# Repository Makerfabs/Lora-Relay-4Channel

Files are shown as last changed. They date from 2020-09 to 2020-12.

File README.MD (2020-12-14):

 Lora-Relay-4Channel
 ==
Introduce
-
4-Channel Lora Relay-10A based on the Arduino, users can program it with Arduino IDE, which is very easy especially suit for the none-programmers. There are also guide for users to learn how to create the first IoT project with this board, with which the starters can learn the hardware and programming skill quickly. <br>
[Makerfabs Wiki](https://makerfabs.com/wiki/index.php?title=Main_Page) <br>
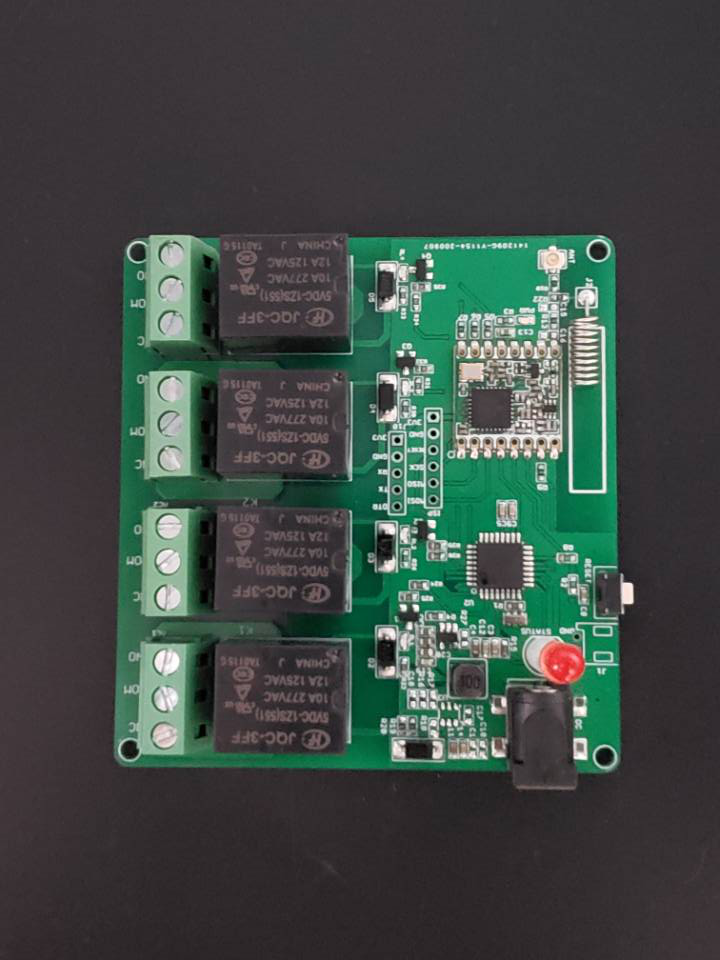
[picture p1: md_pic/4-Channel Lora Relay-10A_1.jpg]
<br/>

Feature
-
* ATMEL Atmega328P: High Performance, Low Power Atmel®AVR® 8-Bit Microcontroller
* Speed Grade:20Mhz
* Flash:32Kbytes
* RAM: 2KBytes
* EEPROM: 1Kbytes
* Relay type: General Purpose 
* Rated current of relay contact: 10A
* Coil type of relay: Non Latching
* Coil voltage of relay: 5V
* Switching voltage of relay: (277VAC , 28VDC) Max
* DC12V or 5V input

Usage
-
 ### Hardware connection
The USB TO UART TOOL is needed to connect the module and PC. <br>
The pins connections is: 
|4-Channel Lora Relay-10A |USB-to-UART Tool |
|---|---|
|3V3 |3V3 |
|GND |GND |
|RX |TXD |
|TX |RXD |

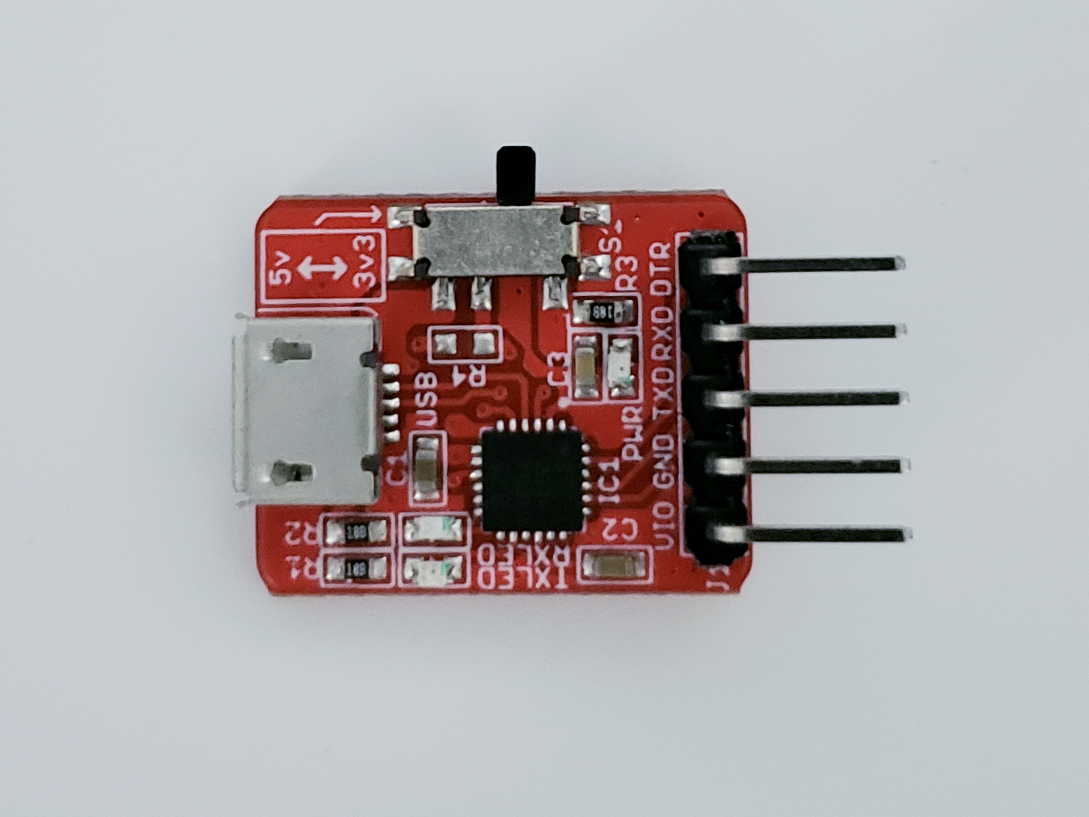
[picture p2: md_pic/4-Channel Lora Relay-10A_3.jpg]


 ### Software setup
Open the Arduino, select the tools menu and set the parameter, as the figure:<br>
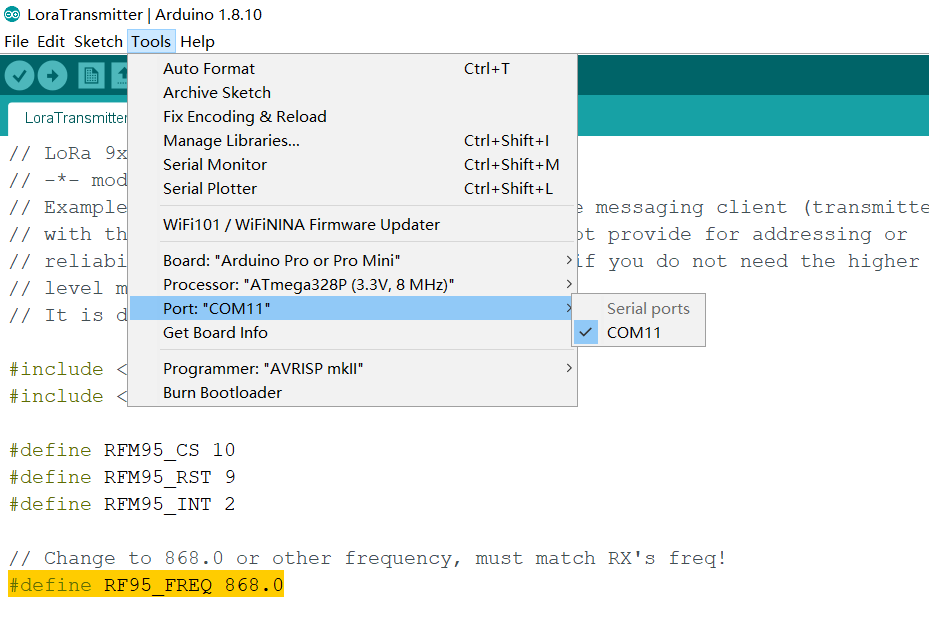
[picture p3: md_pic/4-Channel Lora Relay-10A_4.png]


 ### Lora Transmitter
Prepare a Lora receiver and put it aside.<br>
Open the code "LoraTransmitter/LoraTransmitter.ino" and modify the frequency macro according to your board is 433Mhz or 868Mhz or 915Mhz. <br>
```
#define RF95_FREQ 868.0  
```
Verify and upload it. <br>
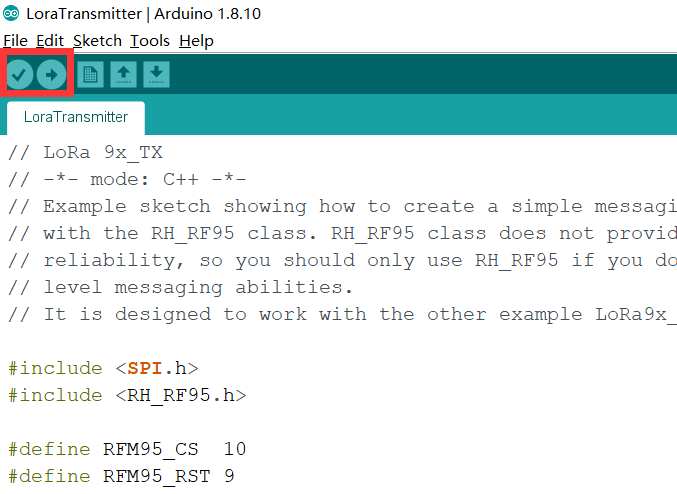
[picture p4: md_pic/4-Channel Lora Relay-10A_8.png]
  <br>
Open the “Tools—Serial Monitor” and the information of Lora Transmitter will be shown in the monitor, as the picture. 
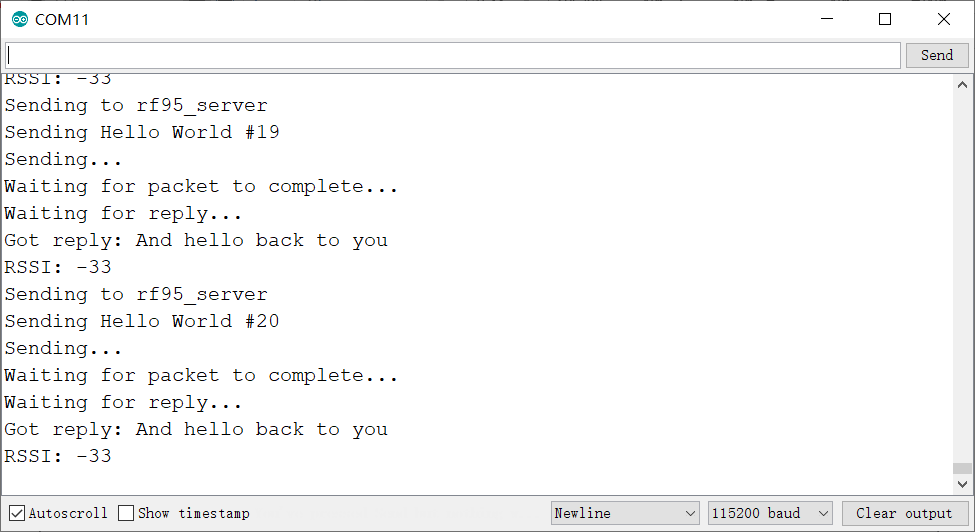
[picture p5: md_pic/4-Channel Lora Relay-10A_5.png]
 

 ### Lora receiver
Open the "LoraReceiver/LoraReceiver.ino" and modify the frequency macro according to your board is 433Mhz or 868Mhz or 915Mhz. 
```
#define RF95_FREQ 868.0 
```
Verify and upload it. After finish, open the “Tools—Serial Monitor”, If have a transmitter next to it, the receive will receive data sent by the Transmitter and the monitor will show the received information in the window, as the picture.
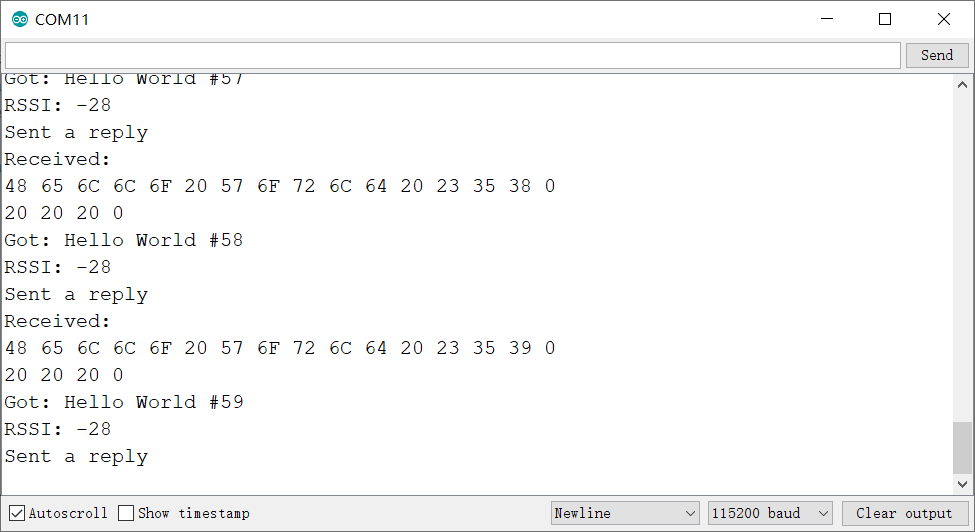
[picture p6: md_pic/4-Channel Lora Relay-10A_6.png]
  <br>
If the receiver has received it, the relay will be turned on or turned off. Light on when COM connect to NO, light off when COM connect to NC and Normally light off.<br>
 <br>
Control relay pins: <br>
|Atmega328P	|Relay |
|---|---|
|D4	|K1 |
|D3	|K2 |
|A3	|K3 |
|A2	|K4 |

The following table lists all of the relay's pins and their functionality.<br>
|Pin	|Description | 
|---|---|
|NC	Normally |Closed | 
|NO	Normally |Opened | 
|COM	|Switch Common |

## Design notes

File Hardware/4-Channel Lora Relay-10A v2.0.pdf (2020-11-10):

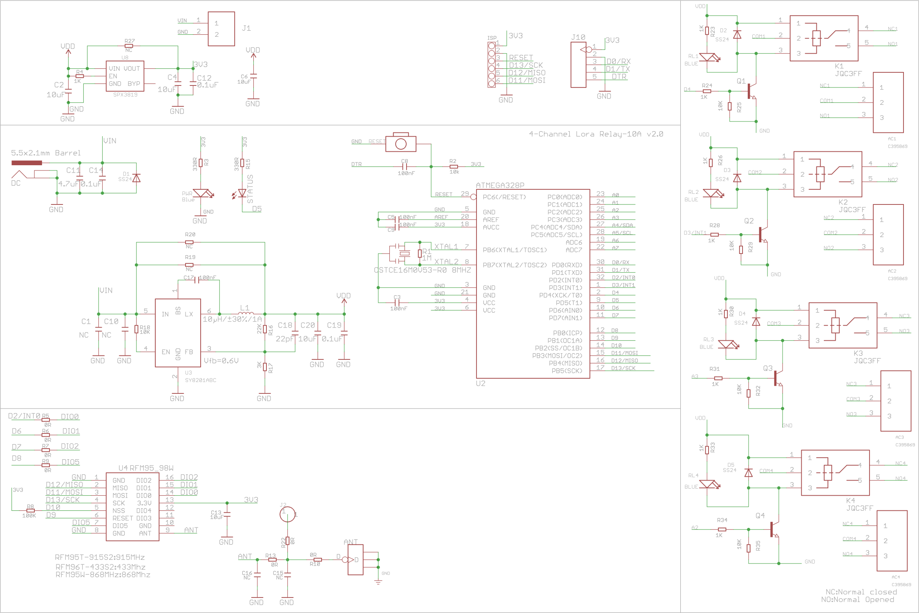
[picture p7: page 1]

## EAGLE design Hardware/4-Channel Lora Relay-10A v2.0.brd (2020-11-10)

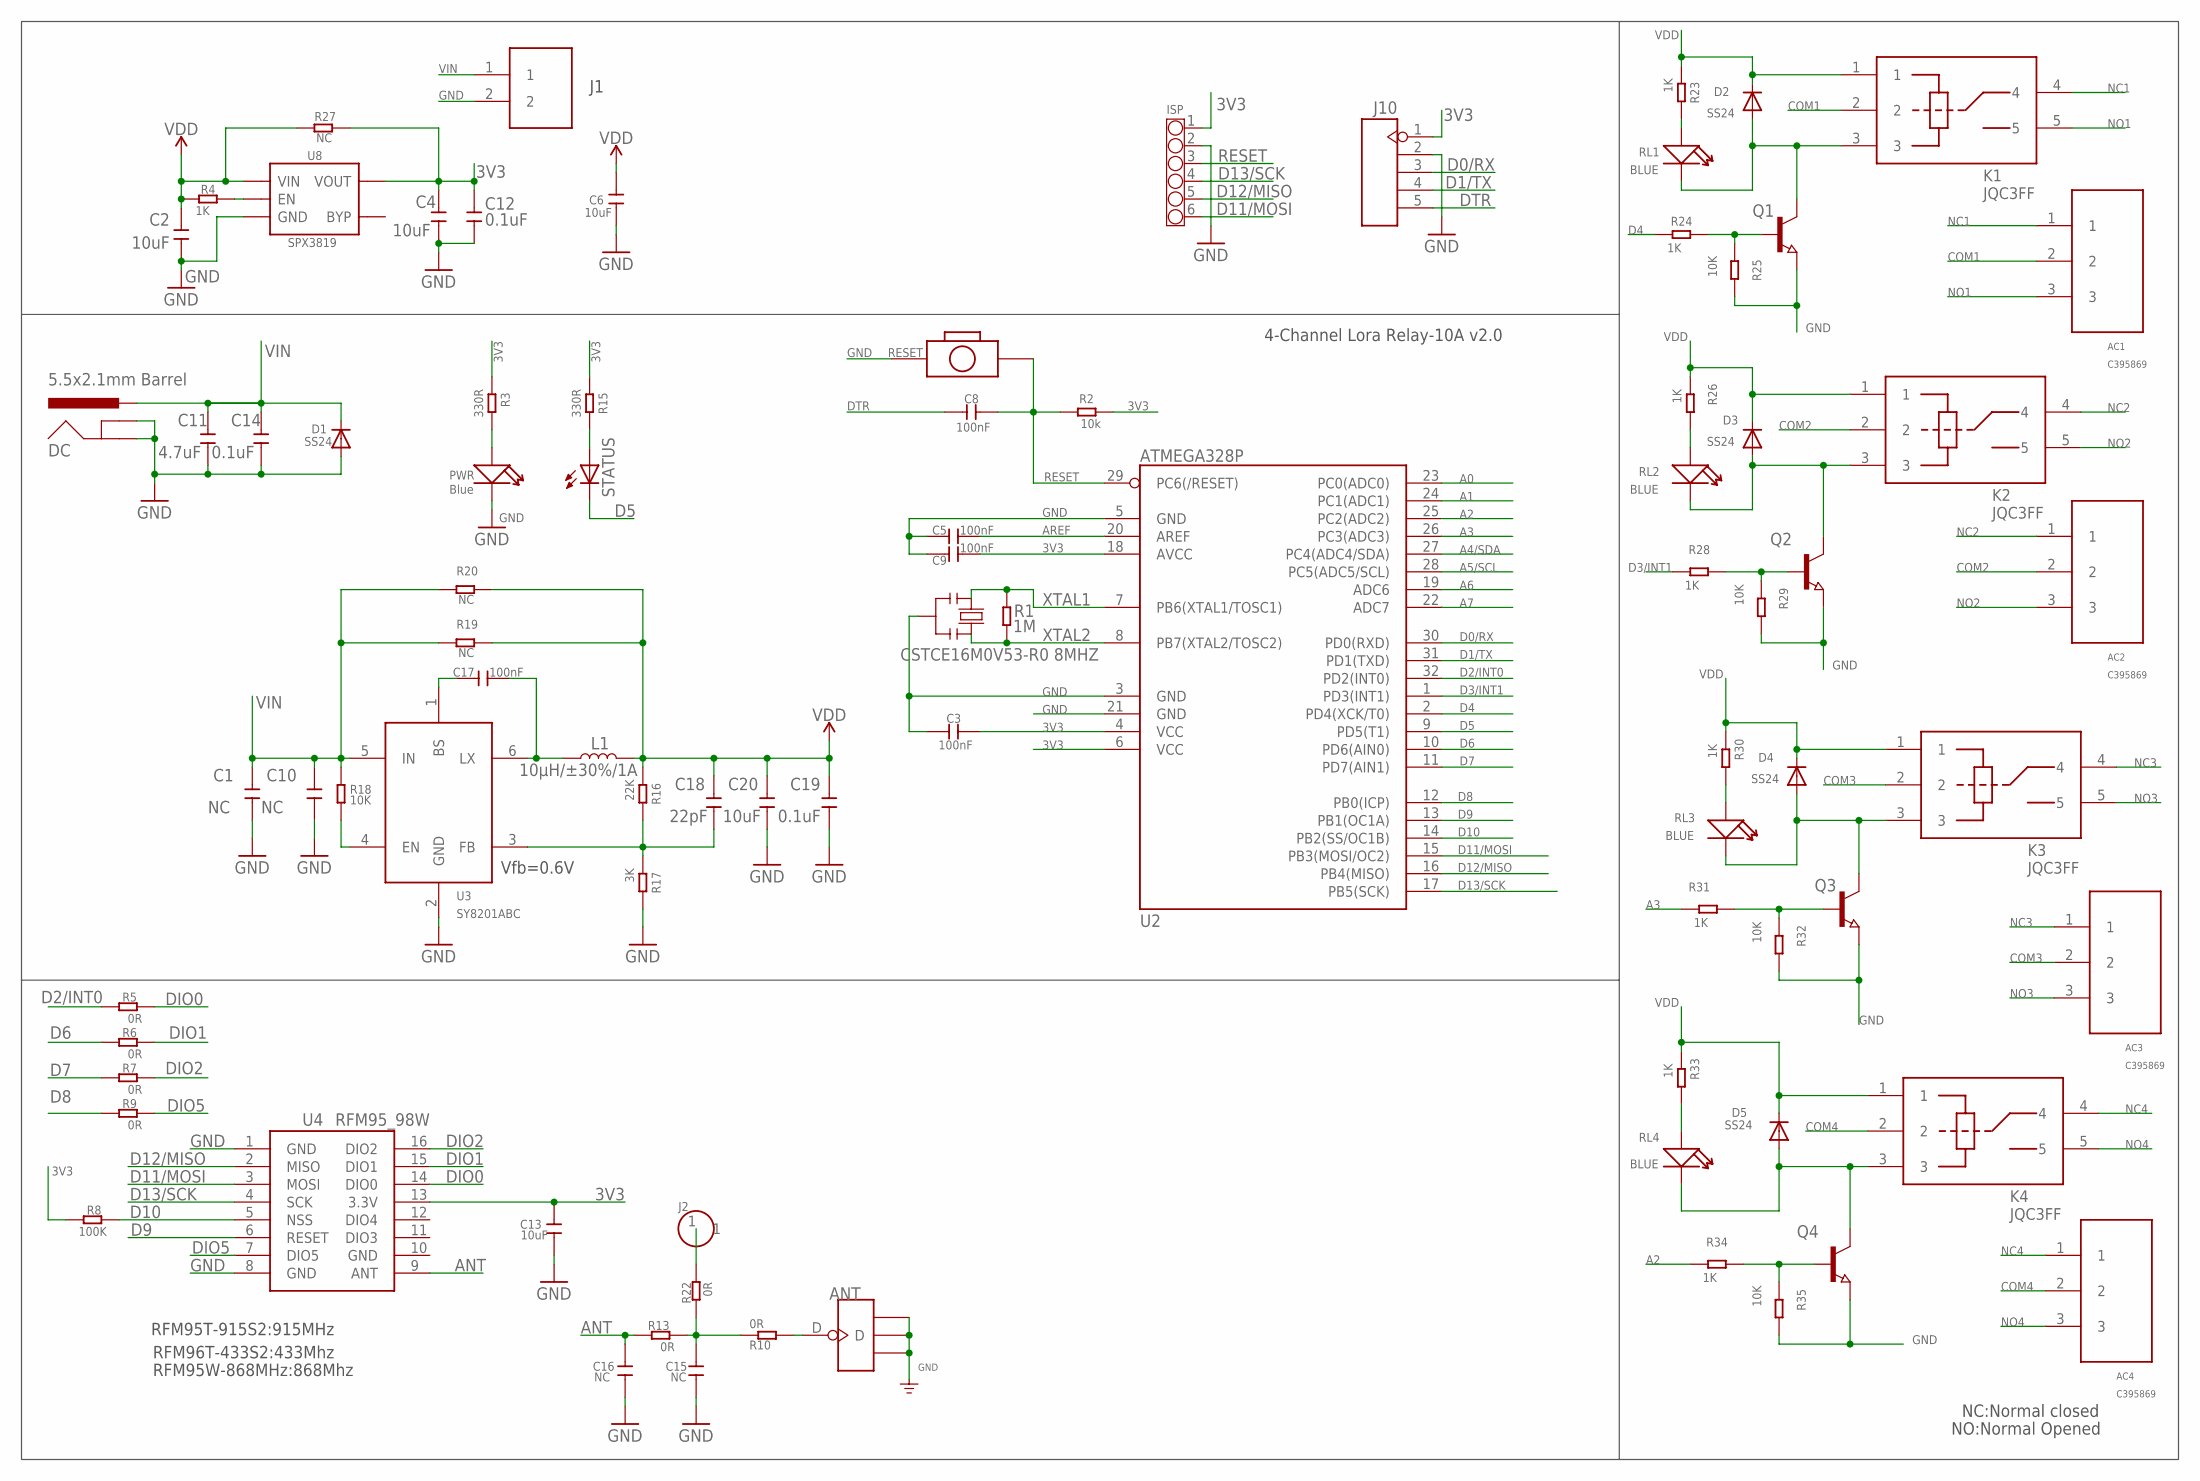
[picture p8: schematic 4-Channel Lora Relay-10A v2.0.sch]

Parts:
AC1, AC2, AC3, AC4: C395869; PIN_3P
ANT: ANTENNA-U-FL; 4P-U-FL
C1, C10, C15, C16: NC; 0603
C2, C4, C6, C13, C20: 10uF; 0603
C3, C5, C8, C9, C17: 100nF; 0603
C11: 4.7uF; 0603
C12, C14, C19: 0.1uF; 0603
C18: 22pF; 0603
D1, D2, D3, D4, D5: SS24; SMADIODE
DC: 5.5x2.1mm Barrel; POWER_JACK_SMD
ISP: CONNECTOR-HEADER-6P-3460270P1; 1X6P-2.54-8.5-BLACK-FEMALE
J1: PH2.0-2P-90-DIP
J2: HEADER-1P-50; 1P-100/50MIL
J10: HEADER-5P-2.54; 5P-2.54
K1, K2, K3, K4: JQC3FF; DIP5_JQC3FF
L1: 10µH/±30%/1A; CR54
PWR: Blue; LED-0603
Q1, Q2, Q3, Q4: NPN-TRANSISTOR_SOT23; SOT23
R1: 1M; R0603
R2: 10k; R0603
R3, R15: 330R; R0603
R4, R23, R24, R26, R28, R30, R31, R33, R34: 1K; R0603
R5, R6, R7, R9, R10, R13, R22: 0R; R0603
R8: 100K; R0603
R16: 22K; R0603
R17: 3K; R0603
R18, R25, R29, R32, R35: 10K; R0603
R19, R20, R27: NC; R0603
RESET: BOTTON-2P-90D; 2P-7.62X3.56-90D
RL1, RL2, RL3, RL4: BLUE; LED-0603
STATUS: LED5MM
U2: ATMEGA328P; TQFP32
U3: SY8201ABC; SOT-23-6
U4: RFM95_98W; RFM92_93W
U8: SPX3819; SOT23-5
Y1: CSTCE16M0V53-R0 8MHZ; RESONATOR

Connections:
3V3: C3.2, C4.2, C9.2, C12.2, C13.2, ISP.1, J10.1, R2.1, R3.1, R8.2, R15.1, R27.2, U2.4 (VCC), U2.6 (VCC), U2.18 (AVCC), U4.13 (3.3V), U8.5 (VOUT)
A0: U2.23 (PC0(ADC0))
A1: U2.24 (PC1(ADC1))
A2: R34.1, U2.25 (PC2(ADC2))
A3: R31.1, U2.26 (PC3(ADC3))
A4/SDA: U2.27 (PC4(ADC4/SDA))
A5/SCL: U2.28 (PC5(ADC5/SCL))
A6: U2.19 (ADC6)
A7: U2.22 (ADC7)
ANT: C16.2, R13.2, U4.9 (ANT)
AREF: C5.2, U2.20 (AREF)
COM1: AC1.2, K1.2
COM2: AC2.2, K2.2
COM3: AC3.2, K3.2
COM4: AC4.2, K4.2
D0/RX: J10.3, U2.30 (PD0(RXD))
D1/TX: J10.4, U2.31 (PD1(TXD))
D2/INT0: R5.1, U2.32 (PD2(INT0))
D3/INT1: R28.1, U2.1 (PD3(INT1))
D4: R24.1, U2.2 (PD4(XCK/T0))
D5: STATUS.K (C), U2.9 (PD5(T1))
D6: R6.1, U2.10 (PD6(AIN0))
D7: R7.1, U2.11 (PD7(AIN1))
D8: R9.1, U2.12 (PB0(ICP))
D9: U2.13 (PB1(OC1A)), U4.6 (RESET)
D10: R8.1, U2.14 (PB2(SS/OC1B)), U4.5 (NSS)
D11/MOSI: ISP.6, U2.15 (PB3(MOSI/OC2)), U4.3 (MOSI)
D12/MISO: ISP.5, U2.16 (PB4(MISO)), U4.2 (MISO)
D13/SCK: ISP.4, U2.17 (PB5(SCK)), U4.4 (SCK)
DIO0: R5.2, U4.14 (DIO0)
DIO1: R6.2, U4.15 (DIO1)
DIO2: R7.2, U4.16 (DIO2)
DIO5: R9.2, U4.7 (DIO5)
DTR: C8.1, J10.5
GND: ANT.GND1, ANT.GND2, ANT.GND3, C1.1, C2.1, C3.1, C4.1, C5.1, C6.1, C9.1, C10.1, C11.1, C12.1, C13.1, C14.1, C15.1, C16.1, C19.1, C20.1, D1.A, DC.GND (GNDBREAK), DC.P$4 (GND), ISP.2, J1.2, J10.2, PWR.-, Q1.2 (E), Q2.2 (E), Q3.2 (E), Q4.2 (E), R17.2, R25.2, R29.2, R32.2, R35.2, RESET.P$1 (1), U2.3 (GND), U2.5 (GND), U2.21 (GND), U3.2 (GND), U4.1 (GND), U4.8 (GND), U4.10 (GND), U8.2 (GND), Y1.2
unnamed: ANT.D, R10.2
unnamed: R23.2, RL1.+
unnamed: C15.2, R10.1, R13.1, R22.2
unnamed: R15.2, STATUS.A
unnamed: C17.2, L1.P$1 (1), U3.6 (LX)
unnamed: PWR.+, R3.2
unnamed: C17.1, U3.1 (BS)
unnamed: D2.A, K1.3, Q1.3 (C), RL1.-
unnamed: C18.1, R16.2, R17.1, U3.3 (FB)
unnamed: R18.2, U3.4 (EN)
unnamed: J2.1, R22.1
unnamed: Q1.1 (B), R24.2, R25.1
unnamed: R26.2, RL2.+
unnamed: D3.A, K2.3, Q2.3 (C), RL2.-
unnamed: Q2.1 (B), R28.2, R29.1
unnamed: R4.2, U8.3 (EN)
unnamed: R30.2, RL3.+
unnamed: D4.A, K3.3, Q3.3 (C), RL3.-
unnamed: Q3.1 (B), R31.2, R32.1
unnamed: R33.2, RL4.+
unnamed: D5.A, K4.3, Q4.3 (C), RL4.-
unnamed: Q4.1 (B), R34.2, R35.1
NC1: AC1.1, K1.4
NC2: AC2.1, K2.4
NC3: AC3.1, K3.4
NC4: AC4.1, K4.4
NO1: AC1.3, K1.5
NO2: AC2.3, K2.5
NO3: AC3.3, K3.5
NO4: AC4.3, K4.5
RESET: C8.2, ISP.3, R2.2, RESET.P$2 (2), U2.29 (PC6(/RESET))
VDD: C2.2, C6.2, C18.2, C19.2, C20.2, D2.C, D3.C, D4.C, D5.C, K1.1, K2.1, K3.1, K4.1, L1.P$2 (2), R4.1, R16.1, R19.2, R20.2, R23.1, R26.1, R27.1, R30.1, R33.1, U8.1 (VIN)
VIN: C1.2, C10.2, C11.2, C14.2, D1.C, DC.VIN0 (PWR), J1.1, R18.1, R19.1, R20.1, U3.5 (IN)
XTAL1: R1.2, U2.7 (PB6(XTAL1/TOSC1)), Y1.1
XTAL2: R1.1, U2.8 (PB7(XTAL2/TOSC2)), Y1.3

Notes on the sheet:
RFM95T-915S2:915MHz
RFM96T-433S2:433Mhz
RFM95W-868MHz:868Mhz
NC:Normal closed
NO:Normal Opened
4-Channel Lora Relay-10A v2.0
Vfb=0.6V

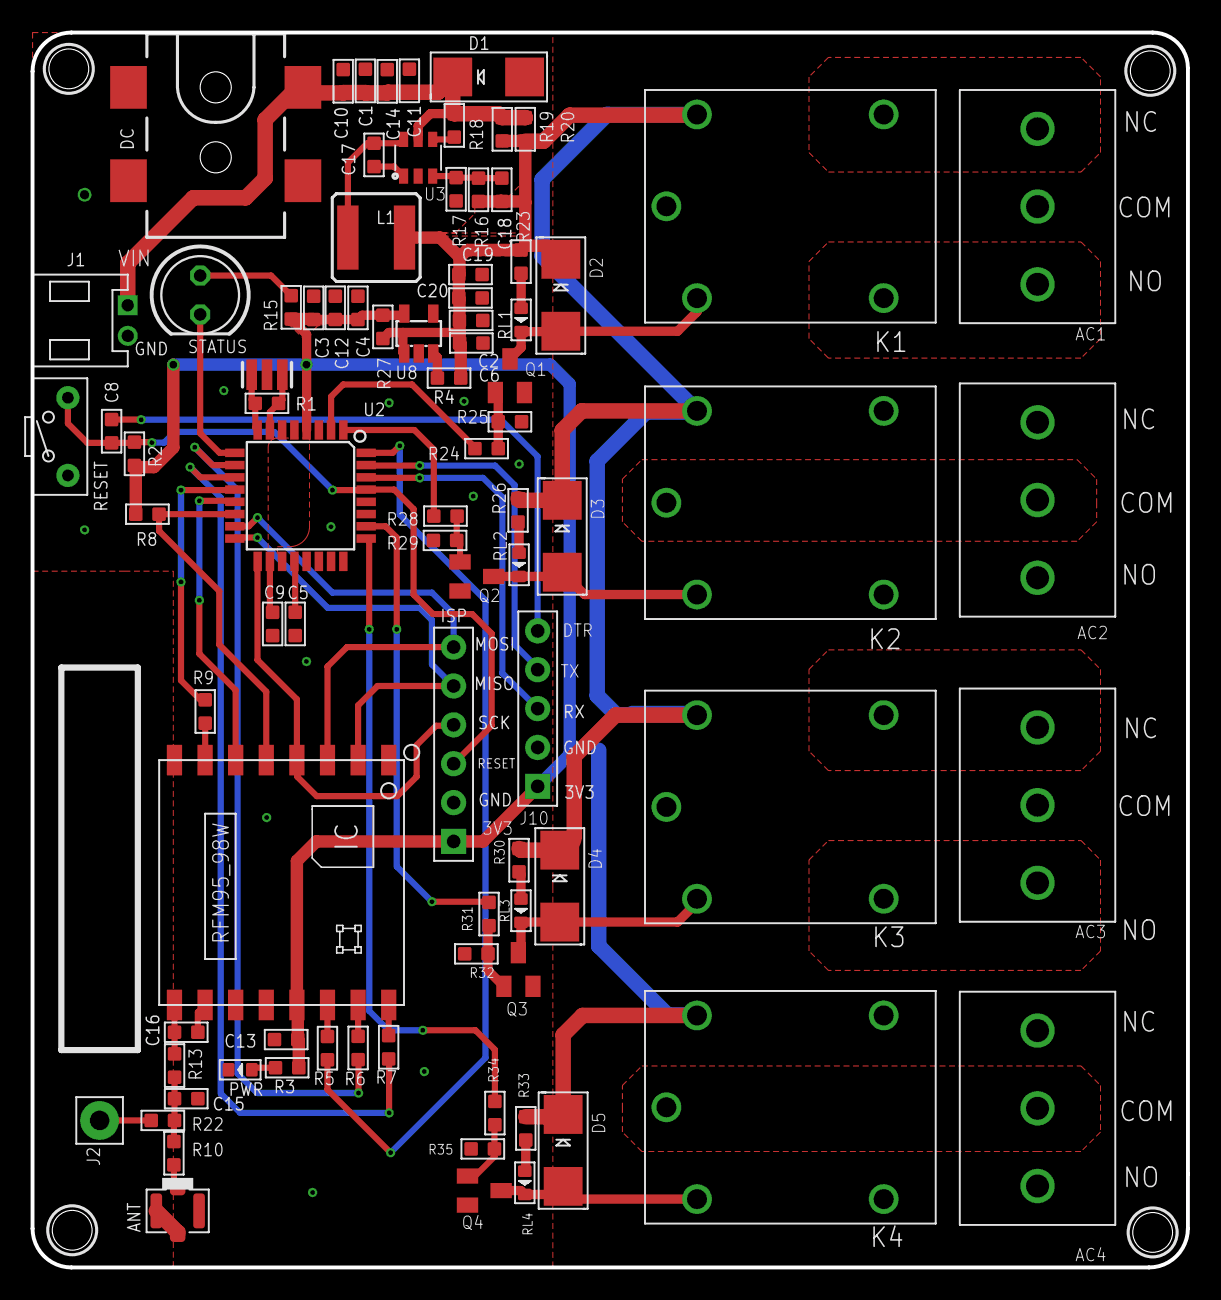
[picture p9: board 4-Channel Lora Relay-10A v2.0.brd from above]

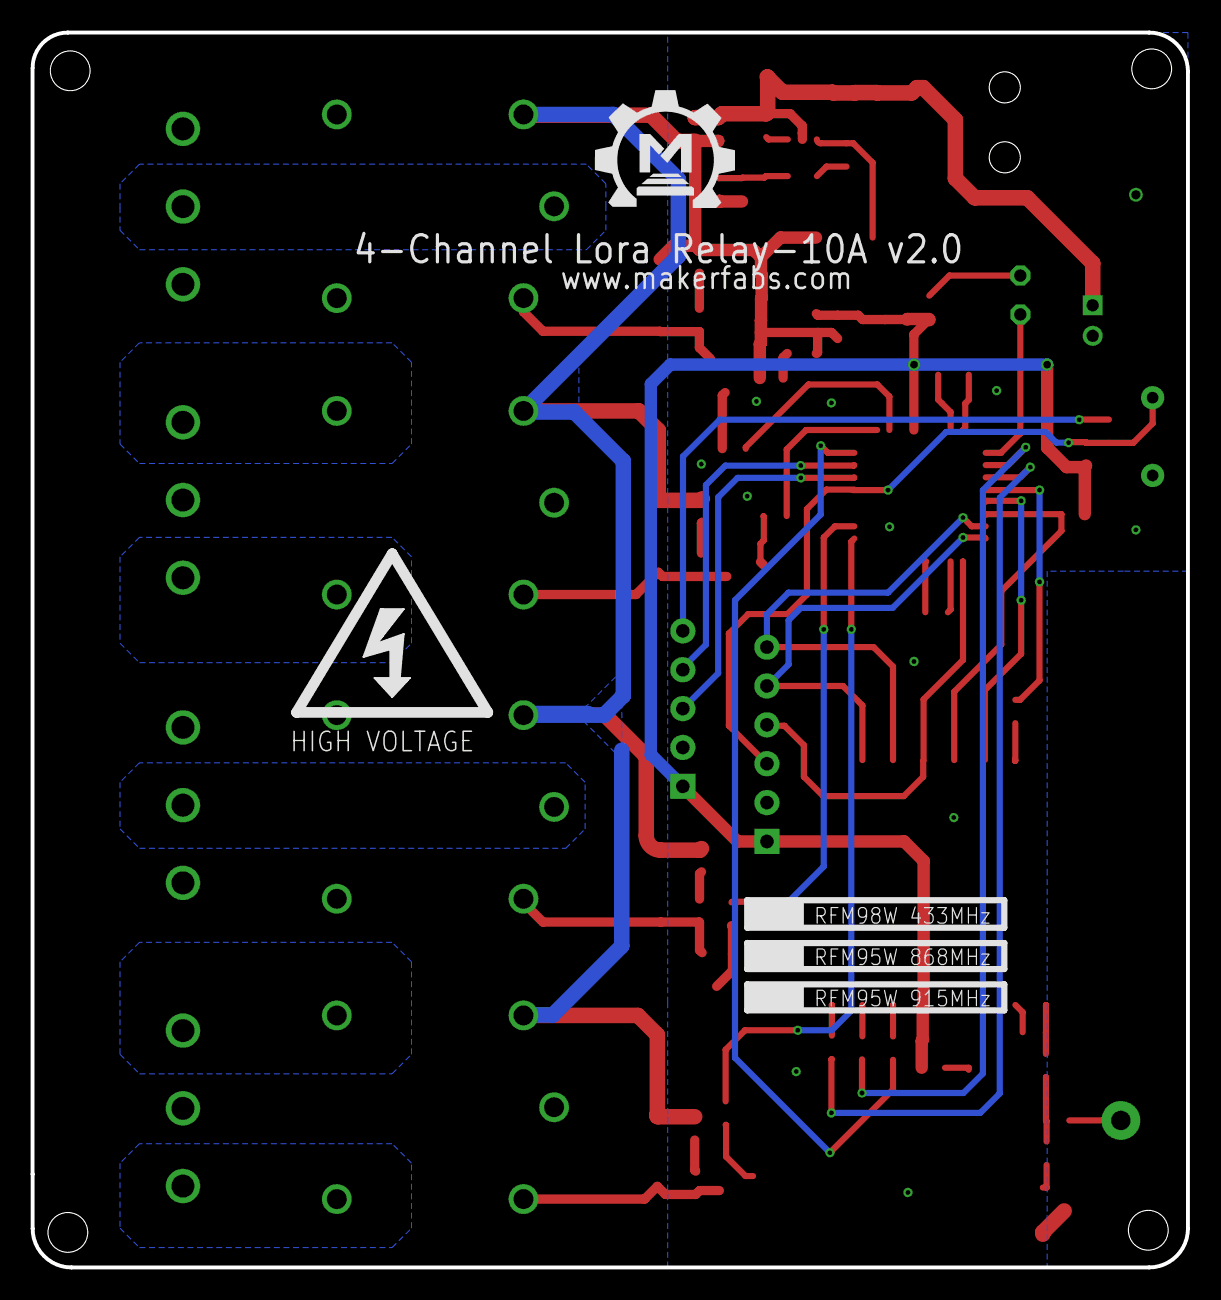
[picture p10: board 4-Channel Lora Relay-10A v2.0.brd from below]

Board: 2 copper layers, 75.5 x 80.7 mm, 88 parts (2 on the bottom side), 64 nets.

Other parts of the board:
U$1: MAKERFABS_0.3
U$3: HIGH-VOLTAGE-1.5

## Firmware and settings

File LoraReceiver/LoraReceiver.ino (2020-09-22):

// Arduino9x_RX
// -*- mode: C++ -*-
// Example sketch showing how to create a simple messaging client (receiver)
// with the RH_RF95 class. RH_RF95 class does not provide for addressing or
// reliability, so you should only use RH_RF95 if you do not need the higher
// level messaging abilities.
// It is designed to work with the other example Arduino9x_TX
 
#include <SPI.h>
#include <RH_RF95.h>
 
#define RFM95_CS 10
#define RFM95_RST 9
#define RFM95_INT 2
 
// Change to 868.0 or other frequency, must match RX's freq!
#define RF95_FREQ 868.0
 
// Singleton instance of the radio driver
RH_RF95 rf95(RFM95_CS, RFM95_INT);
 
// Blinky on receipt
#define LED 5


int count=0;

void TurnOnRelay(void)
{
  digitalWrite(4, HIGH);    //RELAY 1
  digitalWrite(3, HIGH);    //RELAY 2
  digitalWrite(A3, HIGH);   //RELAY 3
  digitalWrite(A2, HIGH);   //RELAY 4

  delay(100);
}

void TurnOffRelay(void)
{
  digitalWrite(4, LOW);
  digitalWrite(3, LOW);
  digitalWrite(A3, LOW);
  digitalWrite(A2, LOW);

  
  delay(100);
}

void setup() 
{
  pinMode(5, OUTPUT);
  pinMode(4, OUTPUT);
  pinMode(3, OUTPUT);
  pinMode(A3, OUTPUT);
  pinMode(A2, OUTPUT);
   
  pinMode(RFM95_RST, OUTPUT);
  digitalWrite(RFM95_RST, HIGH);
 
  //while (!Serial);
  Serial.begin(115200);
  delay(100);
 
  Serial.println("Arduino LoRa RX Test!");
  
  // manual reset
  digitalWrite(RFM95_RST, LOW);
  delay(10);
  digitalWrite(RFM95_RST, HIGH);
  delay(10);
 
  while (!rf95.init()) {
    Serial.println("LoRa radio init failed");
    while (1);
  }
  Serial.println("LoRa radio init OK!");
 
  // Defaults after init are 434.0MHz, modulation GFSK_Rb250Fd250, +13dbM
  if (!rf95.setFrequency(RF95_FREQ)) {
    Serial.println("setFrequency failed");
    while (1);
  }
  Serial.print("Set Freq to: "); Serial.println(RF95_FREQ);
 
  // Defaults after init are 434.0MHz, 13dBm, Bw = 125 kHz, Cr = 4/5, Sf = 128chips/symbol, CRC on
 
  // The default transmitter power is 13dBm, using PA_BOOST.
  // If you are using RFM95/96/97/98 modules which uses the PA_BOOST transmitter pin, then 
  // you can set transmitter powers from 5 to 23 dBm:
  rf95.setTxPower(23, false);
}
 
void loop()
{   
  if (rf95.available())
  {
    
    // Should be a message for us now   
    uint8_t buf[RH_RF95_MAX_MESSAGE_LEN];
    uint8_t len = sizeof(buf);
    
    if (rf95.recv(buf, &len))
    {
      count++;
      digitalWrite(LED, HIGH);
      RH_RF95::printBuffer("Received: ", buf, len);
      Serial.print("Got: ");
      Serial.println((char*)buf);
      Serial.print("RSSI: ");
      Serial.println(rf95.lastRssi(), DEC);

      if(count%2==1)
        TurnOnRelay();
      else
        TurnOffRelay();
       
      // Send a reply
      uint8_t data[] = "And hello back to you";
      rf95.send(data, sizeof(data));
      rf95.waitPacketSent();
      Serial.println("Sent a reply");
      digitalWrite(LED, LOW);
    }
    else
    {
      Serial.println("Receive failed");
    }
  }
}

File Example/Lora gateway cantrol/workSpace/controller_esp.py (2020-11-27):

#MakePython ESP32 对象文件
from machine import Pin, SPI, reset
import config_lora
import controller 
 

class Controller(controller.Controller):

    # LoRa config
    PIN_ID_FOR_LORA_RESET = 33

    PIN_ID_FOR_LORA_SS = 32
    PIN_ID_SCK = 14 
    PIN_ID_MOSI = 13 
    PIN_ID_MISO = 12 

    PIN_ID_FOR_LORA_DIO0 = 36
    PIN_ID_FOR_LORA_DIO1 = None 
    PIN_ID_FOR_LORA_DIO2 = None 
    PIN_ID_FOR_LORA_DIO3 = None
    PIN_ID_FOR_LORA_DIO4 = None
    PIN_ID_FOR_LORA_DIO5 = None  
    
    
    # ESP config
    if config_lora.IS_ESP8266:
        ON_BOARD_LED_PIN_NO = 2
        ON_BOARD_LED_HIGH_IS_ON = False
        GPIO_PINS = (0, 1, 2, 3, 4, 5, 12, 13, 14, 15, 16) 
        
    if config_lora.IS_ESP32:
        ON_BOARD_LED_PIN_NO = 2
        ON_BOARD_LED_HIGH_IS_ON = True
        GPIO_PINS = (0, 1, 2, 3, 4, 5, 6, 7, 8, 9, 10, 11,
                     12, 13, 14, 15, 16, 17, 18, 19, 21, 22,
                     23, 25, 26, 27, 32, 34, 35, 36, 37, 38, 39) 

    #构造函数
    def __init__(self,   
                 pin_id_led = ON_BOARD_LED_PIN_NO, 
                 on_board_led_high_is_on = ON_BOARD_LED_HIGH_IS_ON,
                 pin_id_reset = PIN_ID_FOR_LORA_RESET,
                 blink_on_start = (2, 0.5, 0.5)):

        #调用父类构造函数即controller        
        super().__init__(pin_id_led,
                         on_board_led_high_is_on,
                         pin_id_reset,
                         blink_on_start)

        
    def prepare_pin(self, pin_id, in_out = Pin.OUT):
        if pin_id is not None:
            pin = Pin(pin_id, in_out)
            new_pin = Controller.Mock()
            new_pin.pin_id = pin_id
            new_pin.value = pin.value
            
            if in_out == Pin.OUT:
                new_pin.low = lambda : pin.value(0)
                new_pin.high = lambda : pin.value(1)        
            else:
                new_pin.irq = pin.irq 
                
            return new_pin

            
    def prepare_irq_pin(self, pin_id): 
        pin = self.prepare_pin(pin_id, Pin.IN) 
        if pin:
            pin.set_handler_for_irq_on_rising_edge = lambda handler: pin.irq(handler = handler, trigger = Pin.IRQ_RISING)
            pin.detach_irq = lambda : pin.irq(handler = None, trigger = 0)
            return pin
            
            
    def get_spi(self): 
        spi = None
        id = 1
        
        if config_lora.IS_ESP8266:
            spi = SPI(id, baudrate = 10000000, polarity = 0, phase = 0)
            spi.init()
            
        if config_lora.IS_ESP32:
            try:
                if config_lora.SOFT_SPI: id = -1#soft spi
                else: id = 1#hardware spi      
                spi = SPI(id, baudrate = 10000000, polarity = 0, phase = 0, bits = 8, firstbit = SPI.MSB,
                          sck = Pin(self.PIN_ID_SCK, Pin.OUT, Pin.PULL_DOWN),
                          mosi = Pin(self.PIN_ID_MOSI, Pin.OUT, Pin.PULL_UP),
                          miso = Pin(self.PIN_ID_MISO, Pin.IN, Pin.PULL_UP))
                spi.init()
                    
            except Exception as e:
                print(e)
                if spi: 
                    spi.deinit()
                    spi = None
                reset()  # in case SPI is already in use, need to reset. 
        
        return spi
        
            
    def prepare_spi(self, spi): 
        if spi:
            new_spi = Controller.Mock()  

            def transfer(pin_ss, address, value = 0x00):        
                response = bytearray(1)

                pin_ss.low()
                 
                spi.write(bytes([address]))
                spi.write_readinto(bytes([value]), response)

                pin_ss.high()

                return response
                
            new_spi.transfer = transfer
            new_spi.close = spi.deinit            
            return new_spi
            
        
    def __exit__(self): 
        self.spi.close()
        

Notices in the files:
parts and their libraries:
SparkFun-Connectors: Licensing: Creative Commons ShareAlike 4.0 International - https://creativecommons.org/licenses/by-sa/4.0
